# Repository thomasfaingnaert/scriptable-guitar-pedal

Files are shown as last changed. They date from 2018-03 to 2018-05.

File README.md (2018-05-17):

# A scriptable guitar pedal

## Building
### GNU/Linux (native compilation)
The following instructions are for Debian-based distributions.
Change the commands according to the distribution you are using.

1. Install the following prerequisites:
  - CMake
  - GNU Toolchain
  - Make
```bash
sudo apt-get update
sudo apt-get upgrade
sudo apt-get install cmake build-essential
```

2. Clone the repository and build the project:
```bash
git clone https://github.com/thomasfaingnaert/scriptable-guitar-pedal
mkdir build
cd build
cmake ../scriptable-guitar-pedal
make
```

3. Run the executable:
```bash
chmod +x ./scriptable-guitar-pedal
./scriptable-guitar-pedal
```

### Windows (cross compilation)
1. Install the following prerequisites, and make sure they are in your PATH:
  - CMake (https://cmake.org/)
  - Beaglebone GNU Toolchain (http://gnutoolchains.com/beaglebone/)
  - NMake (included in Visual Studio or Microsoft Visual C++ Build Tools)
  - PuTTY (https://www.putty.org/)

2. Clone the repository and build the project:
```powershell
git clone https://github.com/thomasfaingnaert/scriptable-guitar-pedal
mkdir build
cd build
cmake -G"NMake Makefiles" -DCMAKE_TOOLCHAIN_FILE="../scriptable-guitar-pedal/cmake/Toolchain.cmake" ../scriptable-guitar-pedal
nmake
```

### GNU/Linux (cross compilation)
1. Install the following prerequisites:
  - CMake
  - GNU Toolchain for ARM
  - Make

If you are using Ubuntu or one of its derivatives:
```bash
sudo apt install make cmake binutils-arm-linux-gnueabihf gcc-arm-linux-gnueabihf g++-arm-linux-gnueabihf
```

If you are using Fedora:
```bash
sudo dnf copr enable lantw44/arm-linux-gnueabihf-toolchain
sudo dnf install make cmake arm-linux-gnueabihf-{binutils,gcc,glibc}
```

Otherwise, change the commands according to the distribution you are using.

2. Clone the repository and build the project:
```bash
git clone https://github.com/thomasfaingnaert/scriptable-guitar-pedal
mkdir build
cd build
cmake -DCMAKE_TOOLCHAIN_FILE="../scriptable-guitar-pedal/cmake/Toolchain.cmake" ../scriptable-guitar-pedal
make
```

## Configuring the PRU
These instructions are for the Beaglebone image [Debian 9.3 2018-03-05 4GB SD IoT](http://debian.beagleboard.org/images/bone-debian-9.3-iot-armhf-2018-03-05-4gb.img.xz).
They may or may not work for you if you use a different one.

1. Make sure you can access the internet on the BeagleBone Black.
This can be done by configuring your internet adapter on your PC to share its connection with the Beaglebone.
Create a script `internet.sh` with the following contents:
```bash
#!/usr/bin/env bash
route add default gw 192.168.7.1
echo "nameserver 8.8.8.8" >> /etc/resolv.conf
```
Finally, run the script with sudo:
```bash
chmod +x ./internet.sh
sudo ./internet.sh
```

2. Update all packages:
```bash
sudo apt update
sudo apt upgrade
```

3. Delete RoboticsCape, as it blacklists the `uio_pruss` module
```bash
sudo apt purge roboticscape
```

4. Apply the Xenomai patches to the kernel using:
```bash
cd /opt/scripts/tools/
git pull
sudo ./update_kernel.sh --ti-xenomai-kernel --lts-4_9
sudo reboot
```
Finally, you can check if you are running the right kernel using:
```bash
uname -a
```
This should output something similar to `Linux beaglebone 4.9.88-ti-xenomai-r107 #1 SMP PREEMPT Sat Mar 24 09:29:27 UTC 2018 armv7l GNU/Linux`.

5. Next, we need to install our custom overlay:
```bash
cd device-tree/
make
sudo make install
```

6. Enable it by copying `uEnv-pru.txt` to the `boot/` folder:
```bash
cd boot/
sudo cp uEnv-pru.txt /boot/uEnv.txt
```

7. The UIO driver should now be loaded. You can verify this by running:
```bash
lsmod | grep uio
ls /dev/uio*
```

8. If you want to assemble PRU Assembly files on your PC, you should install the PRU assembler from https://github.com/beagleboard/am335x_pru_package.
Otherwise, you could copy the `*.p` files to the BBB using SCP and assemble them there.
To assemble a file `test.p`, you can use:
```bash
pasm -b test.p
```

9. Install the RTDM kernel module from https://github.com/thomasfaingnaert/rtdm_pruss_irq:
```bash
wget https://github.com/thomasfaingnaert/rtdm_pruss_irq/releases/download/v1.0/rtdm_pruss_irq.ko
sudo cp rtdm_pruss_irq.ko /lib/modules/`uname -r`/extra
sudo depmod -a
sudo modprobe rtdm_pruss_irq
```

10. Run the PRU loader to execute the PRU code:
```bash
./scriptable-guitar-pedal test.bin
```

## Building the ASoC codec driver

### GNU/Linux - Fedora (cross compilation)
These instructions are for Fedora based distributions.
Change the commands according to the distribution you are using.

1. Clone the official BeagleBoard and BeagleBone kernel repository and checkout the version the BeagleBone is running:
```bash
git clone https://github.com/beagleboard/linux
cd linux
git checkout 4.9.82-ti-r102
```

2. Make sure you have no stale .o files and dependencies lying around:
```bash
make mrproper
```

3. Modularize the ASoC codec driver:
```bash
mkdir ../build
make O=../build ARCH=arm bb.org_defconfig
make O=../build ARCH=arm menuconfig
```
Navigate to `Device Drivers/Sound Card Support/Advanced Linux Sound Architecture/ALSA for SoC audio support/CODEC drivers`
and modularize Cirrus Logic CS4271 CODEC (I2C).

4. Compile the kernel:
```bash
make O=../build ARCH=arm CROSS_COMPILE=arm-linux-gnueabihf-
```

5. Copy the modules on your to the BeagleBone Black:
```bash
scp ../build/sound/soc/codecs/snd-soc-cs4271-i2c.ko ../build/sound/soc/codecs/snd-soc-cs4271.ko debian@beaglebone.local:~
```

6. Install the modules on the BeagleBone Black:
```bash
ssh debian@beaglebone.local
sudo mv snd-soc-cs4271-i2c.ko snd-soc-cs4271.ko /lib/modules/4.9.82-ti-r102/extra/
sudo depmod -a
```

## Transferring to BeagleBone Black
To transfer the executable to your BeagleBone Black, you can use SSH, e.g. using PSCP (PuTTY Secure Copy) on Windows or SCP (Secure Copy) on GNU/Linux:
1. Copy the executable on your computer to the BeagleBone Black:
```powershell
pscp scriptable-guitar-pedal debian@192.168.7.2:/home/debian/scriptable-guitar-pedal
```
If you are using scp, change `pscp` to `scp`.
Also make sure to change the username (`debian`), destination path (`/home/debian/scriptable-guitar-pedal`) and IP address (`192.168.7.2`) if required.

2. Log in to the BeagleBone Black using SSH, and run the application:
```bash
chmod +x ./scriptable-guitar-pedal
./scriptable-guitar-pedal
```

## Using a custom Ne10 installation
The repository already includes a version of Ne10 in `include/ne10` and `lib/libNE10.a`.
If you want to use a custom Ne10 installation, you have to set the CMake variables `NE10_INCLUDE_DIRS` and `NE10_LIBRARIES` to point to the Ne10 include directory and library file, respectively.
An example when cross compiling on Windows:
```powershell
cmake -G"NMake Makefiles" -DCMAKE_TOOLCHAIN_FILE="../scriptable-guitar-pedal/cmake/Toolchain.cmake" -DNE10_INCLUDE_DIRS="/path/to/ne10/inc" -DNE10_LIBRARIES="/path/to/ne10/build/modules/libNE10.a" ../scriptable-guitar-pedal
```

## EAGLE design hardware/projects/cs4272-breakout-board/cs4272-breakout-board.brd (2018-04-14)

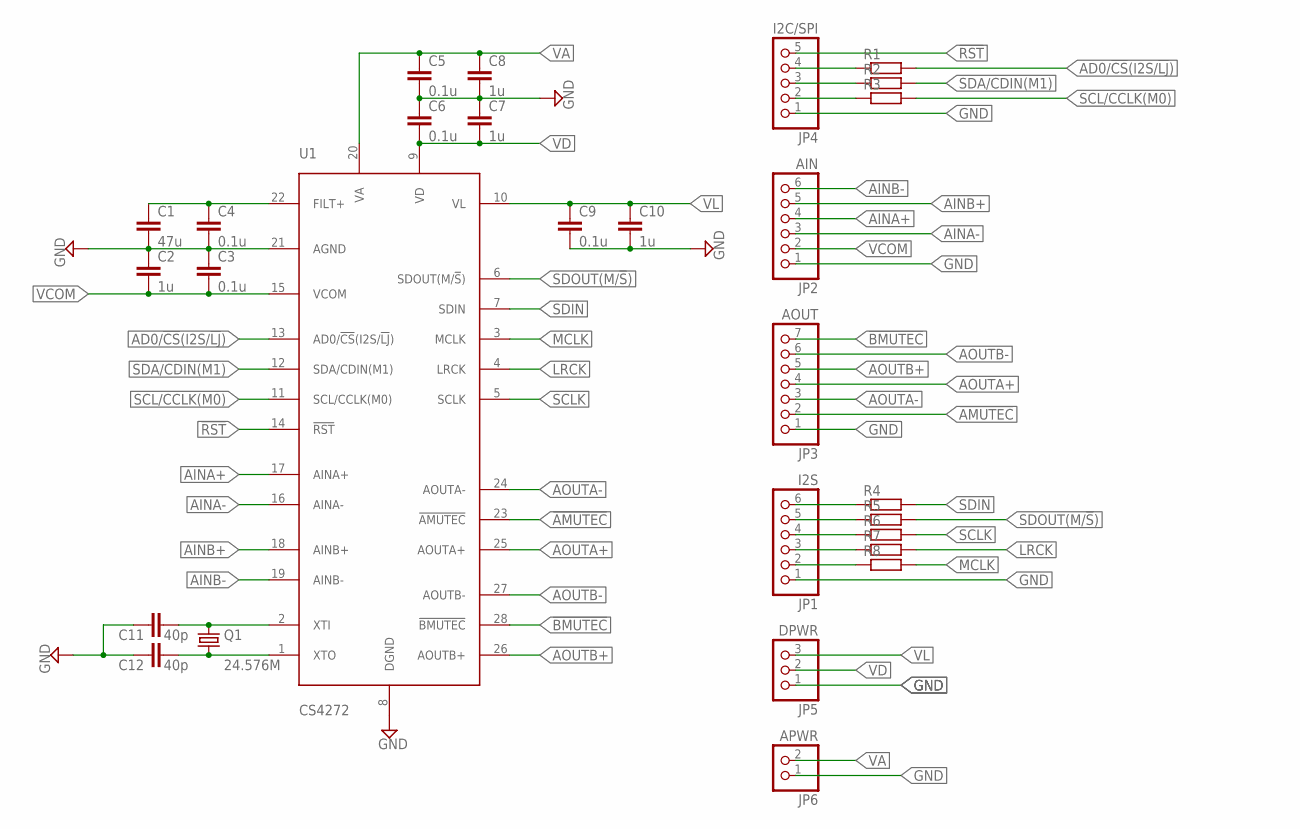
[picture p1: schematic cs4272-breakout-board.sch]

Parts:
C1: 47u; C0603
C2, C7, C8, C10: 1u; C0603
C3, C4, C5, C6, C9: 0.1u; C0603
C11, C12: 40p; C0603
JP1: I2S; 1X06
JP2: AIN; 1X06
JP3: AOUT; 1X07
JP4: I2C/SPI; 1X05
JP5: DPWR; 1X03
JP6: APWR; 1X02
Q1: 24.576M; HC49/S
R1, R2, R3, R4, R5, R6, R7, R8: R-EU_R0603; R0603
U1: CS4272; SOP65P640X120-28

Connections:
!AMUTEC!: JP3.2, U1.23 (!AMUTEC!)
!BMUTEC!: JP3.7, U1.28 (!BMUTEC!)
!RST!: JP4.5, U1.14 (!RST!)
AD0/!CS!(I2S/!LJ!): R1.2, U1.13 (AD0/!CS!(I2S/!LJ!))
AINA+: JP2.4, U1.17 (AINA+)
AINA-: JP2.3, U1.16 (AINA-)
AINB+: JP2.5, U1.18 (AINB+)
AINB-: JP2.6, U1.19 (AINB-)
AOUTA+: JP3.4, U1.25 (AOUTA+)
AOUTA-: JP3.3, U1.24 (AOUTA-)
AOUTB+: JP3.5, U1.26 (AOUTB+)
AOUTB-: JP3.6, U1.27 (AOUTB-)
FILT+: C1.1, C4.1, U1.22 (FILT+)
GND: C1.2, C2.1, C3.1, C4.2, C5.2, C6.1, C7.1, C8.2, C9.2, C10.2, C11.1, C12.1, JP1.1, JP2.1, JP3.1, JP4.1, JP5.1, JP6.1, U1.8 (DGND), U1.21 (AGND)
LRCK: R7.2, U1.4 (LRCK)
MCLK: R8.2, U1.3 (MCLK)
unnamed: JP4.4, R1.1
unnamed: JP4.3, R2.1
unnamed: JP4.2, R3.1
unnamed: JP1.2, R8.1
unnamed: JP1.3, R7.1
unnamed: JP1.4, R6.1
unnamed: JP1.5, R5.1
unnamed: JP1.6, R4.1
SCL/CCLK(M0): R3.2, U1.11 (SCL/CCLK(M0))
SCLK: R6.2, U1.5 (SCLK)
SDA/CDIN(M1): R2.2, U1.12 (SDA/CDIN(M1))
SDIN: R4.2, U1.7 (SDIN)
SDOUT(M/!S!): R5.2, U1.6 (SDOUT(M/!S!))
VA: C5.1, C8.1, JP6.2, U1.20 (VA)
VCOM: C2.2, C3.2, JP2.2, U1.15 (VCOM)
VD: C6.2, C7.2, JP5.2, U1.9 (VD)
VL: C9.1, C10.1, JP5.3, U1.10 (VL)
XTI: C11.2, Q1.2, U1.2 (XTI)
XTO: C12.2, Q1.1, U1.1 (XTO)

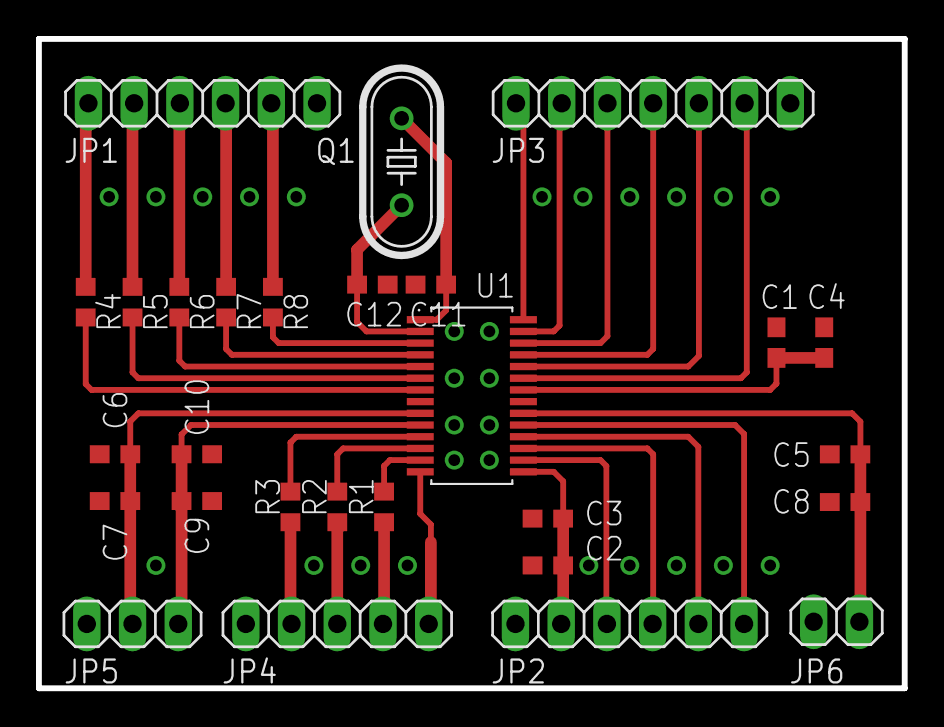
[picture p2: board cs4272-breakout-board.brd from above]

Board: 2 copper layers, 48.1 x 36.1 mm, 28 parts (0 on the bottom side), 35 nets.

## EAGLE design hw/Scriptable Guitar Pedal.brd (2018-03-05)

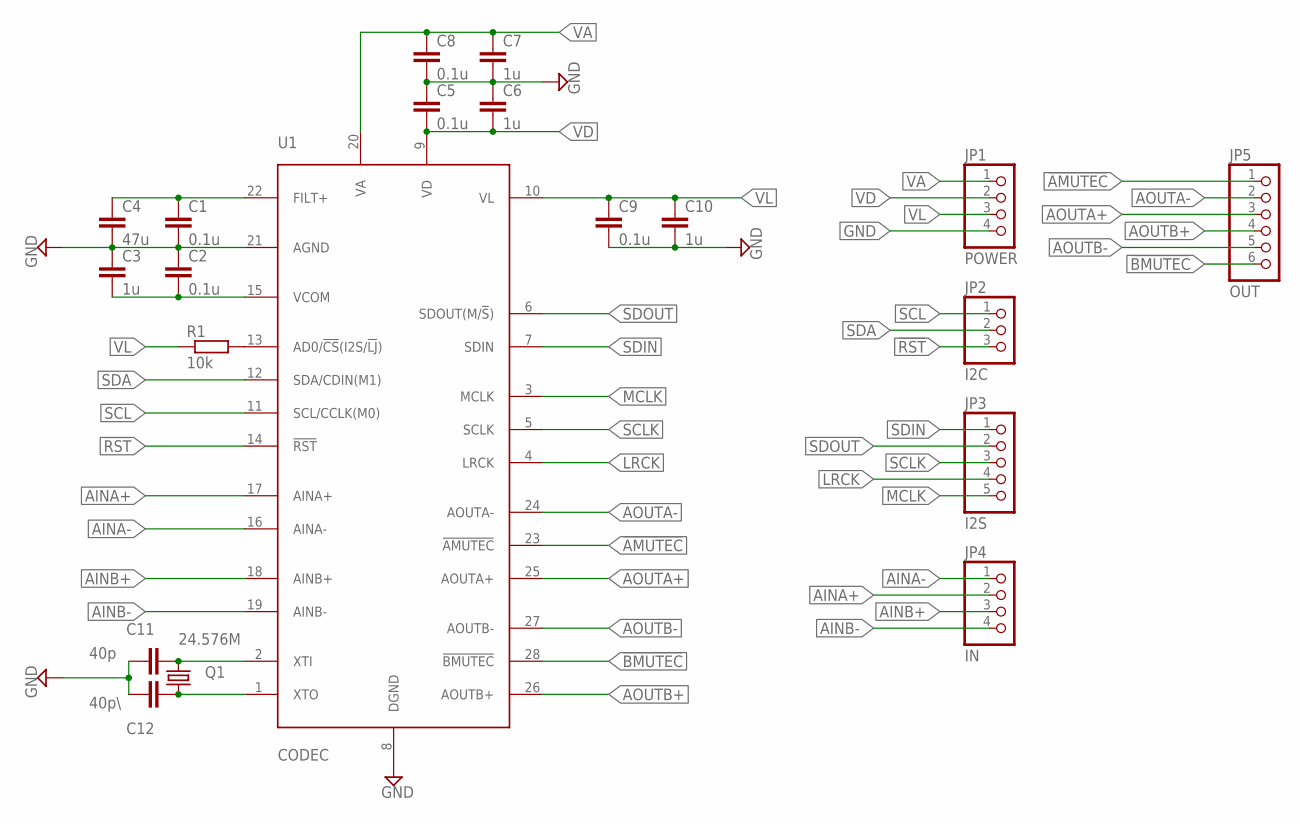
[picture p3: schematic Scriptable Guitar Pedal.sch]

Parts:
C1, C2, C5, C8, C9: 0.1u; C0603
C3, C6, C7, C10: 1u; C0603
C4: 47u; C0603
C11: 40p; C0603
C12: 40p\; C0603
JP1: POWER; 1X04
JP2: I2C; 1X03
JP3: I2S; 1X05
JP4: IN; 1X04
JP5: OUT; 1X06
Q1: 24.576M; HC49U-V
R1: 10k; R0603
U1: CODEC; TSSOP-28

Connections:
!AMUTEC!: JP5.1, U1.23 (!AMUTEC!)
!BMUTEC!: JP5.6, U1.28 (!BMUTEC!)
!RST!: JP2.3, U1.14 (!RST!)
AINA+: JP4.2, U1.17 (AINA+)
AINA-: JP4.1, U1.16 (AINA-)
AINB+: JP4.3, U1.18 (AINB+)
AINB-: JP4.4, U1.19 (AINB-)
AOUTA+: JP5.3, U1.25 (AOUTA+)
AOUTA-: JP5.2, U1.24 (AOUTA-)
AOUTB+: JP5.4, U1.26 (AOUTB+)
AOUTB-: JP5.5, U1.27 (AOUTB-)
FILT+: C1.1, C4.1, U1.22 (FILT+)
GND: C1.2, C2.1, C3.1, C4.2, C5.1, C6.1, C7.2, C8.2, C9.2, C10.2, C11.1, C12.1, JP1.4, U1.8 (DGND), U1.21 (AGND)
LRCK: JP3.4, U1.4 (LRCK)
MCLK: JP3.5, U1.3 (MCLK)
unnamed: C12.2, Q1.1, U1.1 (XTO)
unnamed: C11.2, Q1.2, U1.2 (XTI)
unnamed: R1.2, U1.13 (AD0/!CS!(I2S/!LJ!))
SCL: JP2.1, U1.11 (SCL/CCLK(M0))
SCLK: JP3.3, U1.5 (SCLK)
SDA: JP2.2, U1.12 (SDA/CDIN(M1))
SDIN: JP3.1, U1.7 (SDIN)
SDOUT: JP3.2, U1.6 (SDOUT(M/!S!))
VA: C7.1, C8.1, JP1.1, U1.20 (VA)
VCOM: C2.2, C3.2, U1.15 (VCOM)
VD: C5.2, C6.2, JP1.2, U1.9 (VD)
VL: C9.1, C10.1, JP1.3, R1.1, U1.10 (VL)

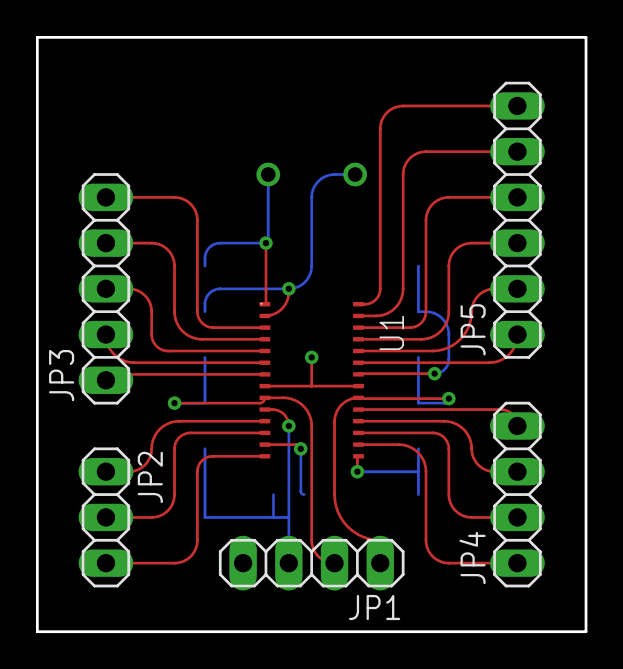
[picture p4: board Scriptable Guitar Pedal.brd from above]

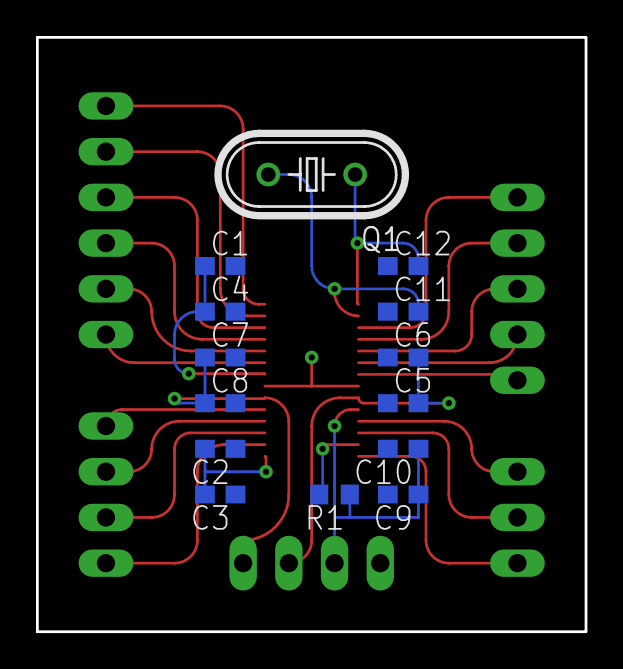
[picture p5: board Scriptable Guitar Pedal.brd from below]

Board: 2 copper layers, 30.5 x 33.0 mm, 20 parts (14 on the bottom side), 27 nets.

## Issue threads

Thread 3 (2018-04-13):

MiniConvolver not copyable

thomasfaingnaert, 2018-04-13:
MiniConvolver segfaults when copied in the FilterEffect ctor.
This is a reminder to figure out later why this is.

thomasfaingnaert, 2018-05-05:
This issue is no longer relevant as the implementation of FilterEffect has changed.

Closed 2018-05-05.

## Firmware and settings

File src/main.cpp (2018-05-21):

#include <chrono>
#include <cstdlib>
#include <cstring>
#include <iostream>
#include <pthread.h>
#include <thread>

#include "NE10.h"
#include "codec.h"
#include "delayeffect.h"
#include "distortioneffect.h"
#include "filesink.h"
#include "filesource.h"
#include "filtereffect.h"
#include "prudevice.h"
#include "sampledata.h"
#include "tremoloeffect.h"
#include "webserver.h"

int main(int argc, char *argv[])
{
    // NE10 Initialisation
    if (ne10_init() != NE10_OK)
    {
        std::cerr << "Could not initialise Ne10." << std::endl;
        return EXIT_FAILURE;
    }

    // Set thread priority
#if 1
    sched_param param;
    param.sched_priority = 99;

    if (pthread_setschedparam(pthread_self(), SCHED_FIFO, &param) != 0)
    {
        std::cerr << "Failed to set priority for thread: Error code " << errno << ": " << std::strerror(errno) << std::endl;
        return EXIT_FAILURE;
    }
#endif

    // Webserver
    WebServer server(8888);
    server.alsa_thread();

    //auto alsaDevice = WebServer::getAlsaDevice();

    /*
    float mainCoeff = 1.0;
    std::vector<unsigned int> delays;
    std::vector<float> coeffs;
    float decay = 0.4;

    int i = 1;
    while (decay >= 0.05)
    {
        delays.push_back(48000/2 * i++);
        coeffs.push_back(decay);
        decay *= decay;
    }

    auto effect = std::make_shared<DelayEffect>(mainCoeff, delays, coeffs);
    */

/*
    auto effect = std::make_shared<DistortionEffect>(8,2,1,0.5);

*/
    /*
    auto effect = std::make_shared<TremoloEffect>(0.4, 48000 / 6);
*/

/*
    SampleData filter("rev.wav");

    std::vector<float> reverb = filter.getSamples()[0];

    for(float& sample : reverb)
        sample /= 75;

    auto effect = std::make_shared<FilterEffect>(reverb);
   */
/*
    alsaDevice->connect(effect);
    effect->connect(alsaDevice);


    while(alsaDevice->generate_next());
*/

    return EXIT_SUCCESS;
}

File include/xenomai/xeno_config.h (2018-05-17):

/* include/xeno_config.h.  Generated from xeno_config.h.in by configure.  */
/* include/xeno_config.h.in.  Generated from configure.ac by autoheader.  */

/* config */
#define CONFIG_MMU 1

/* config */
#define CONFIG_SMP 1

/* config */
/* #undef CONFIG_XENO_ASYNC_CANCEL */

/* config */
#define CONFIG_XENO_BUILD_ARGS " '-enable-smp'"

/* Build system alias */
#define CONFIG_XENO_BUILD_STRING "armv7l-unknown-linux-gnueabihf"

/* config */
#define CONFIG_XENO_COBALT 1

/* Compiler */
#define CONFIG_XENO_COMPILER "gcc version 6.3.0 20170516 (Debian 6.3.0-18+deb9u1) "

/* config */
/* #undef CONFIG_XENO_COPPERPLATE_CLOCK_RESTRICTED */

/* config */
/* #undef CONFIG_XENO_DEBUG */

/* config */
/* #undef CONFIG_XENO_DEBUG_FULL */

/* config */
#define CONFIG_XENO_DEFAULT_PERIOD 1000000

/* config */
#define CONFIG_XENO_FORTIFY 1

/* Host system alias */
#define CONFIG_XENO_HOST_STRING "armv7l-unknown-linux-gnueabihf"

/* config */
/* #undef CONFIG_XENO_LIBS_DLOPEN */

/* config */
#define CONFIG_XENO_LORES_CLOCK_DISABLED 1

/* config */
/* #undef CONFIG_XENO_MERCURY */

/* config */
#define CONFIG_XENO_PREFIX "/usr/xenomai"

/* config */
/* #undef CONFIG_XENO_PSHARED */

/* config */
#define CONFIG_XENO_RAW_CLOCK_ENABLED 1

/* config */
/* #undef CONFIG_XENO_REGISTRY */

/* config */
/* #undef CONFIG_XENO_REGISTRY_ROOT */

/* config */
#define CONFIG_XENO_REVISION_LEVEL 6

/* config */
#define CONFIG_XENO_SANITY 1

/* config */
#define CONFIG_XENO_TLSF 1

/* TLS model */
#define CONFIG_XENO_TLS_MODEL "initial-exec"

/* config */
#define CONFIG_XENO_UAPI_LEVEL 14

/* config */
/* #undef CONFIG_XENO_VALGRIND_API */

/* config */
#define CONFIG_XENO_VERSION_MAJOR 3

/* config */
#define CONFIG_XENO_VERSION_MINOR 0

/* config */
#define CONFIG_XENO_VERSION_NAME "Stellar Parallax"

/* config */
#define CONFIG_XENO_VERSION_STRING "3.0.6"

/* config */
/* #undef CONFIG_XENO_WORKAROUND_CONDVAR_PI */

/* config */
/* #undef CONFIG_XENO_X86_VSYSCALL */

#ifdef __IN_XENO__

/* Define to 1 if you have the `backtrace' function. */
#define HAVE_BACKTRACE 1

/* Define to 1 if you have the `clock_nanosleep' function. */
#define HAVE_CLOCK_NANOSLEEP 1

/* Define to 1 if you have the declaration of
   `PTHREAD_ERRORCHECK_MUTEX_INITIALIZER_NP', and to 0 if you don't. */
#define HAVE_DECL_PTHREAD_ERRORCHECK_MUTEX_INITIALIZER_NP 1

/* Define to 1 if you have the declaration of `PTHREAD_PRIO_NONE', and to 0 if
   you don't. */
#define HAVE_DECL_PTHREAD_PRIO_NONE 1

/* Define to 1 if you have the declaration of
   `PTHREAD_RECURSIVE_MUTEX_INITIALIZER_NP', and to 0 if you don't. */
#define HAVE_DECL_PTHREAD_RECURSIVE_MUTEX_INITIALIZER_NP 1

/* Define to 1 if you have the <dlfcn.h> header file. */
#define HAVE_DLFCN_H 1

/* Define to 1 if you have the `fork' function. */
#define HAVE_FORK 1

/* Define to 1 if you have the <inttypes.h> header file. */
#define HAVE_INTTYPES_H 1

/* Define to 1 if you have the <memory.h> header file. */
#define HAVE_MEMORY_H 1

/* Define to 1 if you have the <mqueue.h> header file. */
#define HAVE_MQUEUE_H 1

/* Define to 1 if you have the <obstack.h> header file. */
#define HAVE_OBSTACK_H 1

/* Define to 1 if you have the `pthread_atfork' function. */
#define HAVE_PTHREAD_ATFORK 1

/* Define to 1 if you have the `pthread_attr_setaffinity_np' function. */
#define HAVE_PTHREAD_ATTR_SETAFFINITY_NP 1

/* Define to 1 if you have the `pthread_condattr_getclock' function. */
#define HAVE_PTHREAD_CONDATTR_GETCLOCK 1

/* Define to 1 if you have the `pthread_condattr_setclock' function. */
#define HAVE_PTHREAD_CONDATTR_SETCLOCK 1

/* Define to 1 if you have the `pthread_getattr_np' function. */
#define HAVE_PTHREAD_GETATTR_NP 1

/* Define to 1 if you have the `pthread_mutexattr_getprotocol' function. */
#define HAVE_PTHREAD_MUTEXATTR_GETPROTOCOL 1

/* Define to 1 if you have the `pthread_mutexattr_setprotocol' function. */
#define HAVE_PTHREAD_MUTEXATTR_SETPROTOCOL 1

/* Define to 1 if you have the `pthread_mutexattr_setrobust_np' function. */
#define HAVE_PTHREAD_MUTEXATTR_SETROBUST_NP 1

/* Define to 1 if you have the `pthread_setaffinity_np' function. */
#define HAVE_PTHREAD_SETAFFINITY_NP 1

/* Define to 1 if you have the `pthread_setname_np' function. */
#define HAVE_PTHREAD_SETNAME_NP 1

/* Define to 1 if you have the `pthread_spin_lock' function. */
#define HAVE_PTHREAD_SPIN_LOCK 1

/* Define to 1 if you have the `sched_getcpu' function. */
#define HAVE_SCHED_GETCPU 1

/* Define to 1 if you have the `shm_open' function. */
#define HAVE_SHM_OPEN 1

/* Define to 1 if you have the `shm_unlink' function. */
#define HAVE_SHM_UNLINK 1

/* Define to 1 if you have the <stdint.h> header file. */
#define HAVE_STDINT_H 1

/* Define to 1 if you have the <stdlib.h> header file. */
#define HAVE_STDLIB_H 1

/* Define to 1 if you have the <strings.h> header file. */
#define HAVE_STRINGS_H 1

/* Define to 1 if you have the <string.h> header file. */
#define HAVE_STRING_H 1
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

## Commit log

2018-02-07 Add new shorter samples for testing
2018-02-10 Update agc test sample
2018-02-12 Add comb filter (not perfect)
2018-02-13 Change implementation of comb filter (works)
2018-02-13 Add fir, iir, allpass and delay functions for comb filter
2018-02-19 Fix case NE10.h in FindNe10.cmake
2018-02-22 Move effects and samples to separate directory
2018-02-22 Add device tree overlay
2018-02-22 Add I2C boilerplate
2018-02-22 Add I2C test
2018-02-28 Update device tree
2018-03-01 Add device tree overlay build script
2018-03-01 Remove compiled device tree overlay
2018-03-03 Implement FilterEffect response setters
    Add setters for both frequency response and impulse response.
2018-03-05 Add breakout board
    [Scriptable Guitar Pedal.brd, Scriptable Guitar Pedal.sch]
2018-03-08 Update PCB
    [CS4272-breakout-board.brd, CS4272-breakout-board.sch]
2018-03-10 Implement samplebuffer
2018-03-10 Fix processor not working with out-of-sync sources
    [main.cpp]
2018-03-10 Revert "Fix processor not working with out-of-sync sources"
    This reverts commit 471441696a233353490747be03069827129c2b5d.
    [main.cpp]
2018-03-11 Revert "Add profiling code for FFT"
    This reverts commit 608e1569d170db294659e5273c0fe7b4f5bd7c20.
    [main.cpp]
2018-03-12 Avoid copies in FFT Convolver
    [main.cpp]
2018-03-12 Add I2C boilerplate code
2018-03-13 Update I2C interface
2018-03-15 General makeover
    [CS4272-breakout-board.brd, CS4272-breakout-board.sch]
2018-03-16 Update device tree overlays
2018-03-17 Add driver compilation instructions and environment variables U-Boot
2018-03-17 Add driver installation instructions
2018-03-18 Fix POST data handling
    [main.cpp]
2018-03-18 Update device tree overlay
2018-03-19 Add schematic and update library
    [cs4272-breakout-board.sch]
2018-03-21 Update breakout board
    [cs4272-breakout-board.brd, cs4272-breakout-board.sch]
2018-03-21 Remove trace
    [cs4272-breakout-board.brd]
2018-04-10 Add handler for chaining
2018-04-10 Add chaining effects processing
2018-04-11 Test convolution with sound samples
2018-04-11 Add output to main thread
2018-04-13 Test non-uniform filter effect
2018-04-13 Rework basic implementation FilterEffect
    [main.cpp]
2018-04-13 Improve testing code FilterEffect
2018-04-13 Implement custom impulse responses in FilterEffect
2018-04-13 Finish first implementation of FilterEffect
2018-04-13 Update devicetree and fix bug in AlsaSource
    [main.cpp]
2018-04-13 Optimise FilterEffect 1: addition with Neon
2018-04-13 Optimise FilterEffect 2: use deque for buffering
2018-04-13 Add first version of multi-threaded filtereffect
2018-04-13 Revert "Add first version of multi-threaded filtereffect"
    This reverts commit 0d7d93233448671eb1c3c271a3a3e76e0f462d63.
2018-04-13 Revert "Revert "Add first version of multi-threaded filtereffect""
    This reverts commit a2e37236f4b797a65adfd8b66efcb9e583c65c10.
2018-04-13 Try adding prioritites in FilterEffect
2018-04-13 Revert "Try adding prioritites in FilterEffect"
    This reverts commit d1e0810487669c26ab5c30da1566353627f95c8c.
2018-04-13 Revert "Revert "Revert "Add first version of multi-threaded filtereffect"""
    This reverts commit 1a4d17dd755e193daa15bef5d77f2111330f6951.
2018-04-14 Clean up FilterEffect
2018-04-16 Update samplerate
2018-04-17 Add samplerate option to filesink ctor
2018-04-17 Remove hardcoded samplerates from webserver
2018-04-20 Adjust FilterEffect to work with new API
2018-04-20 Improve FilterEffect
2018-04-21 Update webserver to work with new chaining API
2018-04-21 Implement basic PRU timer
2018-04-22 Update chain form handling
    Fix #4
    [main.cpp]
2018-04-22 Reposition send button in modal
2018-04-23 Add chain save
2018-04-23 Use RTDM to wait for PRU interrupt
2018-04-23 Use correct interrupts for RTDM
    [main.cpp]
2018-04-24 Improve saving chains
2018-04-24 Add load chain
2018-04-25 Fix filename Arm NEON complex library
2018-04-26 Add Loading chains
2018-04-28 Fix various UI bugs
    [main.cpp]
2018-04-28 Add connections to loaded chains
2018-04-28 Add current chain save
2018-04-28 Fix FDL not working with multiple impulse fragments
    [main.cpp]
2018-04-28 Print number of partitions in FDL test
2018-04-28 Remove FilterEffect
2018-04-28 Implement basic timing test for FilterEffect
2018-04-28 Set priority of main thread
2018-04-29 Make normalization in SampleData optional
2018-04-29 Add basic multithreading test in FilterEffect
2018-04-29 Remove unnecessary statement in FilterEffect
2018-04-29 Remove output in thread_function
2018-04-29 Initialise data before starting threads
2018-04-29 Reset inputAvailable flag when thread gets input
2018-04-29 Avoid reallocaion of params
    [main.cpp]
2018-04-29 Finish implementing scheduling in FilterEffect
2018-04-29 Optimise worker thread signalling
2018-04-30 Reorder synchronisation instructions in FilterEffect
2018-04-30 Remove debugging output from FilterEffect
2018-04-30 Set priority for each thread
2018-04-30 Implement setting name of FDL threads
2018-04-30 Implement input for FilterEffect
2018-04-30 Implement basic input FilterEffect
2018-04-30 Reorder locking output queue in thread_function
2018-04-30 Avoid dynamic allocation in thread_function
2018-05-02 Add pru0 to exclusive-use, refactor PRU code, finish I2C initialization
2018-05-02 Add multiplication factor to alsa device tree
2018-05-02 Refactor alsa device tree
2018-05-02 Finish ALSA device tree
2018-05-02 Fix error in ALSA device tree and expand PRU device tree
2018-05-02 Rename device tree folder
2018-05-02 Fix syntax error in PRU device tree
2018-05-04 Add Alsa handling in thread
2018-05-05 Fix indentation in FilterEffect
    [main.cpp]
2018-05-05 Couldn't open PCM devices with refactored AlsaDevice
2018-05-05 Update device trees to use new kernel
2018-05-05 Add instructions to install RTDM driver
2018-05-05 Implement pushing samples from PRU to CPU
2018-05-05 Remove old PRU interrupt code
2018-05-11 Add chain handling for convolution
2018-05-21 Fix mistake in html and update alsa
    [main.cpp]
